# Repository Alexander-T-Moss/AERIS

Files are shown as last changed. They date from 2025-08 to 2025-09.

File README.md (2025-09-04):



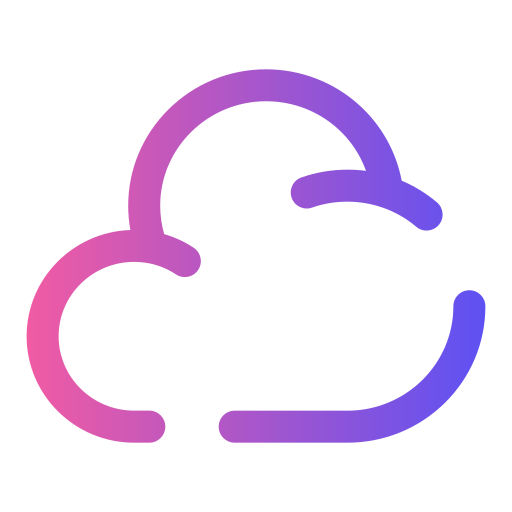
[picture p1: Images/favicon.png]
#  AERIS – Air Quality Monitoring System 






**AERIS** is an open-source air quality monitor built around an **ESP32** microcontroller, **SEN55** module and custom breakout board. It measures and reports environmental parameters, such as particulate matter, VOCs, humidity and temperature in real-time to either a Home Assistant instance (through ESPHome) or a local web app.

<br/>

## Project Goals
- **Accurate & Trustable Data** – Obtained by using the factory-calibrated SEN55 and thermally isolating the unit from the other electronics.
- **Low-Cost** – AERIS' DIY-friendly design approach and BOM considerations result in a unit cost that is more than halved when compared to equivalent off-the-shelf products, at only £35/€40/$48.
- **Full Hardware Utilisation** –  Using any of the provided firmware options, every last bit of information is extracted from AERIS, getting the most "bang-for-buck" out of the used hardware.
- **Simple Assembly** – From a snap-fit case to a breakout PCB, assembly is streamlined to require minimal tools and only a few minutes.
- **Accessible Project** - Care is taken to decrease friction from obtaining hardware to building an AERIS device. Unlike other monitors, AERIS can be used fully as a standalone unit without needing a Home Assistant instance. 

<br/>

## Feature List
<details>
<summary><b>Comprehensive Sensor Array</b></summary>
<br/>

- Temperature
- Relative Humidity
- Absolute Humidity (Approximation)
- VOC Index
- Particulate Matter
  - PM1.0
  - PM2.5
  - PM4.0
  - PM10.0
- Nitrogen Oxide Index (NOx)
- Carbon Dioxide (w/ Add-On Board)
- Atmospheric Pressure (w/ Add-On Board)

</details>

<details>
<summary><b>ESPHome Integration</b></summary>
<br/>  
Requires a Home Assistant instance; alternatively, AERIS can be operated without Home Assistant through its standalone mode.
<br/>
<br/>
</details>

<details>
<summary><b>Standalone Mode</b></summary>
<br/>
The ESP controller can host a local webpage, circumventing the need for a Home Assistant instance.
<br/> 
<br/>
</details>

<details>
<summary><b>1.54" OLED Display</b></summary>
<br/>
Configurable to either show key data at a glance or show in-depth information reported by AERIS.
<br/> 
<br/>
</details>

<details>
<summary><b>Snap-Fit Case</b></summary>
<br/>
For an easy assembly, reduced BOM and clean finish, the case is designed to snap-fit together.
<br/>
<br/>
</details>

<br/>

## More Information
Interested in this project or building an AERIS unit? Visit the [official documentation](https://aeris-docs.xyz) site for more info.

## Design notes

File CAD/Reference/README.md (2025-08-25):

# CAD Reference Sources

[Seeed Studio ESP32C3](https://grabcad.com/library/seeed-studio-xiao-esp32-c3-1) - *Seeed Studio XIAO-ESP32-C3.step*

[Sensirion SEN5x](https://sensirion.com/products/catalog/SEN55) - *Sensirion_STEP_SEN5x.STEP*

[Fan](https://grabcad.com/library/ld3007ms-fan-1) - *3007 5V FAN.step*

[BME280](https://grabcad.com/library/gy-bme280-1) - BME280.step

[SCD41](https://grabcad.com/library/sensirion-scd40-scd41-1) - SCD41.step

[SSD1309](https://grabcad.com/library/serial-spi-i2c-blue-1-54-inch-arduino-raspberry-pi-oled-display-128x64-1) - SSD1309 1.54' I2C.step

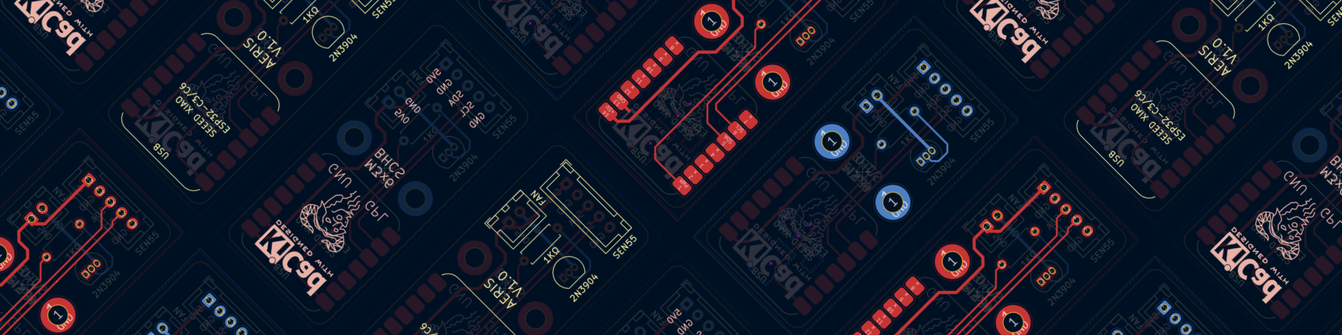
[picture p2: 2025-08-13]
Images/PCB_Schematic_Background.png

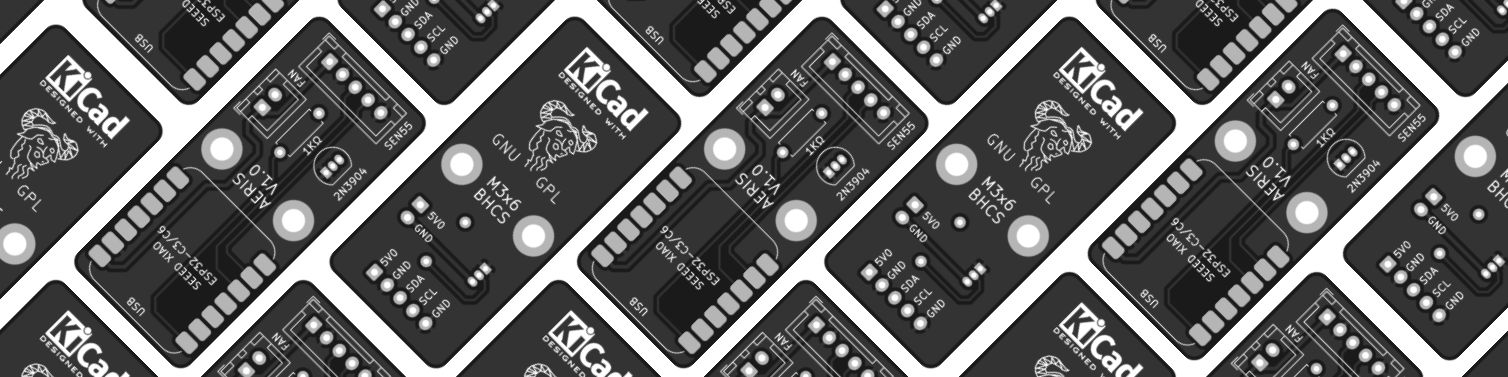
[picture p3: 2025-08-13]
Images/Gerber_Background.png

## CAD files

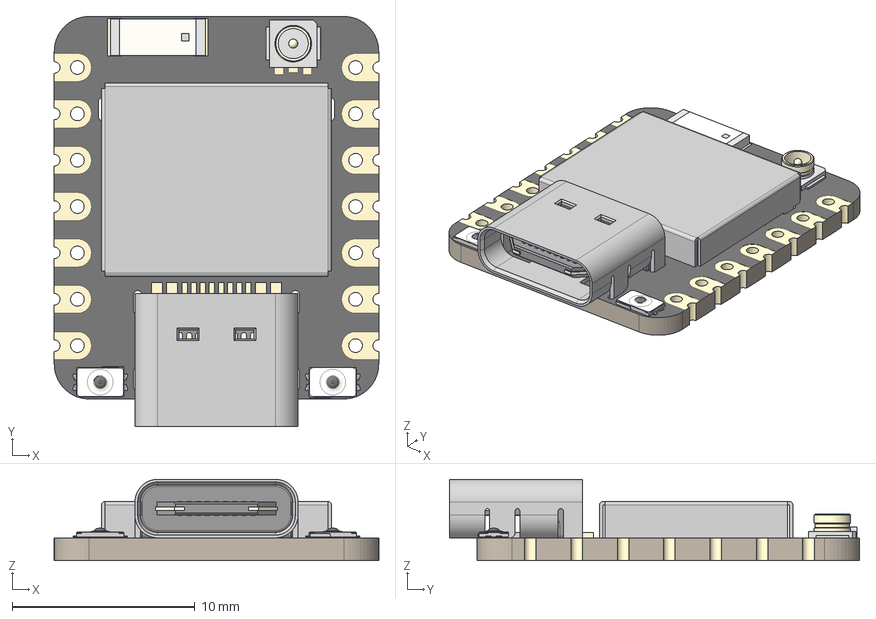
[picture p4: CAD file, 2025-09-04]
CAD/Reference/Seeed Studio XIAO ESP32-C6.step
17.8 x 22.5 x 4.46 mm
BOSS-EXTRUDE14_8_
BOSS-EXTRUDE7_4_
BOSS-EXTRUDE7_3_
BOSS-EXTRUDE14_4_
BOSS-EXTRUDE14_2_
BOSS-EXTRUDE14_11_
BOSS-EXTRUDE7_7_
BOSS-EXTRUDE14_9_
BOSS-EXTRUDE14_3_
BOSS-EXTRUDE14_7_
MIRROR2
BOSS-EXTRUDE14_5_
BOSS-EXTRUDE14_12_
BOSS-EXTRUDE7_8_
BOSS-EXTRUDE7_1_
BOSS-EXTRUDE14_10_
BOSS-EXTRUDE7_9_
BOSS-EXTRUDE14_6_
BOSS-EXTRUDE14_1_
BOSS-EXTRUDE7_6_
BOSS-EXTRUDE7_2_
CUT-EXTRUDE5
BOSS-EXTRUDE7_5_
U.FL Connector v1
Shield
SKTAAAE010 x 2
KH5220-A36 (Ceramic Antenna) v2

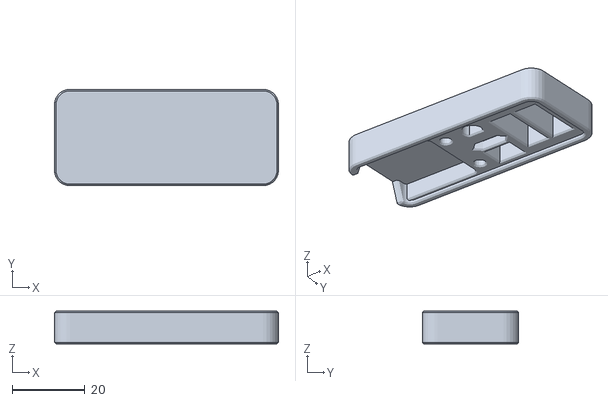
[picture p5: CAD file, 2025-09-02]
STLs/ESP32C3 Breakout Jig.stl
61.4 x 26.4 x 9.00

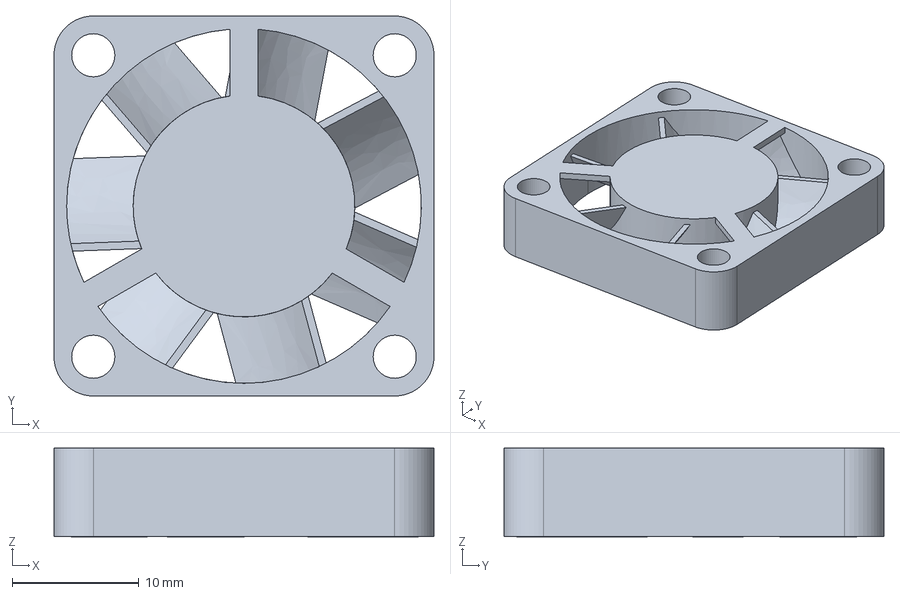
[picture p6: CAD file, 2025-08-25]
CAD/Reference/3007 5V Fan.step
30.0 x 30.0 x 7.02 mm

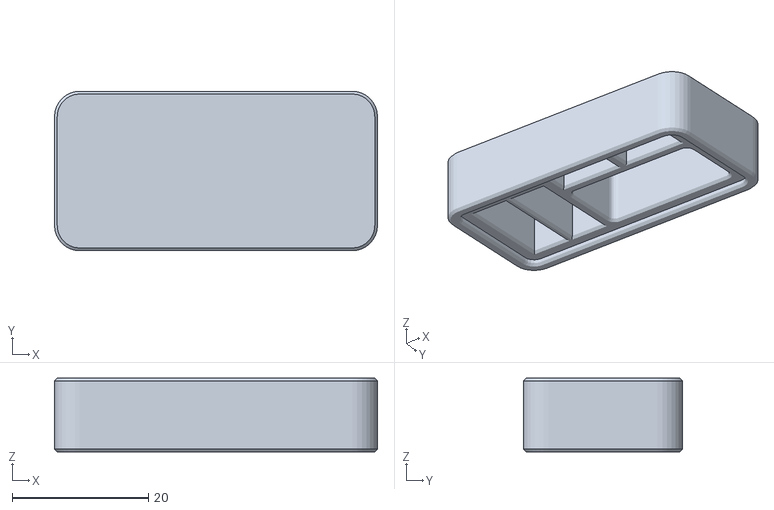
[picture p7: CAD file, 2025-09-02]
STLs/Add-On Solder Jig.stl
47.4 x 23.4 x 10.8

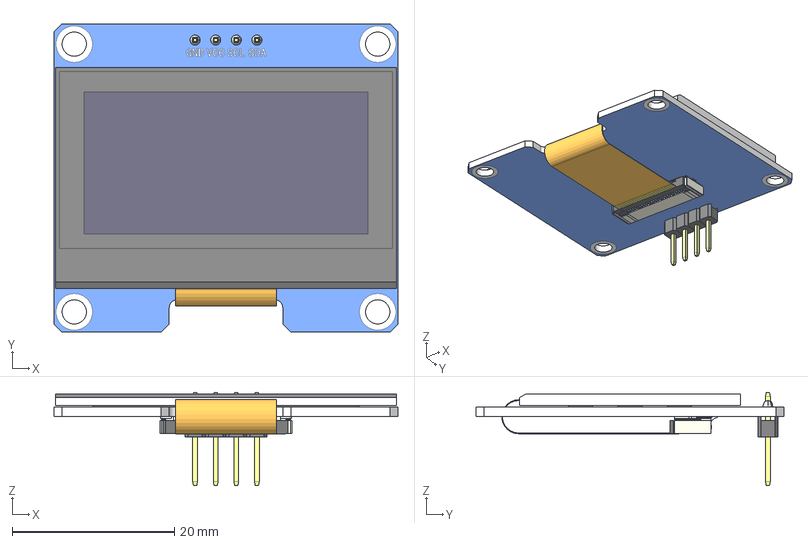
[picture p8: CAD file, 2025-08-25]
CAD/Reference/SSD1309 1.54' I2C.step
42.4 x 38.0 x 11.5 mm
0.15mm x 3
ER-OLEDM015-2-SPI-I2C PCB°å
ER-OLED015-2 (1)
ER-OLED015-2
FPC-24 (16)
FPC-24 (15)
FPC-24 (14)
FPC-24 (13)
FPC-24 (12)
FPC-24 (11)
FPC-24 (10)
FPC-24 (9)
FPC-24 (8)
FPC-24 (7)
FPC-24 (6)
FPC-24 (5)
FPC-24 (4)
FPC-24 (3)
FPC-24 (2)
FPC-24 (1)
FPC-24
Pin Header 7P (6)
Pin Header 7P (5)
Pin Header 7P (4)
Pin Header 7P (3)
Pin Header 7P (2)
Pin Header 7P (1)
Pin Header 7P

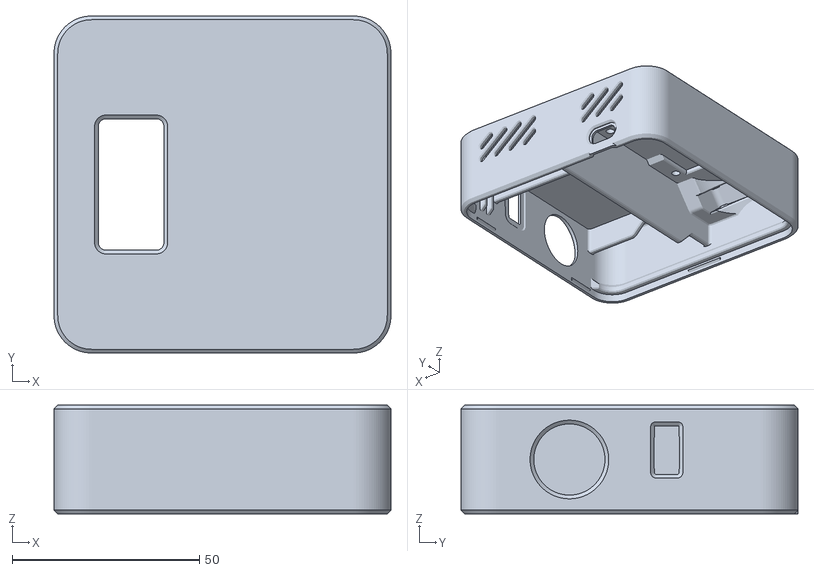
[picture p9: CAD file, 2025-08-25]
STLs/Cover.stl
90.0 x 90.0 x 29.0

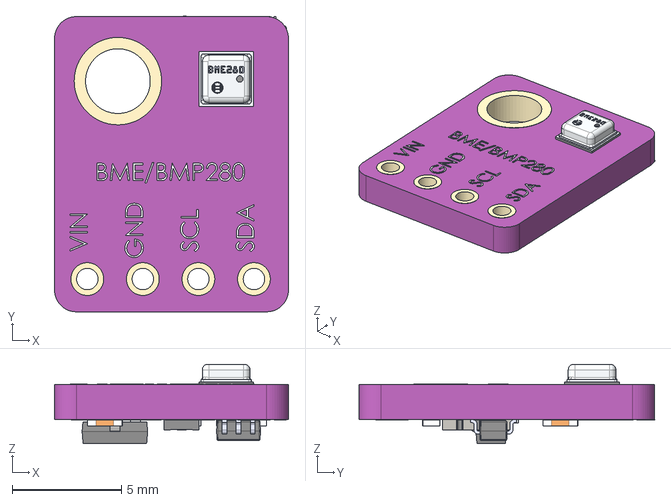
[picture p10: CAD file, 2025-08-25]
CAD/Reference/BME280.step
10.7 x 13.5 x 3.63 mm

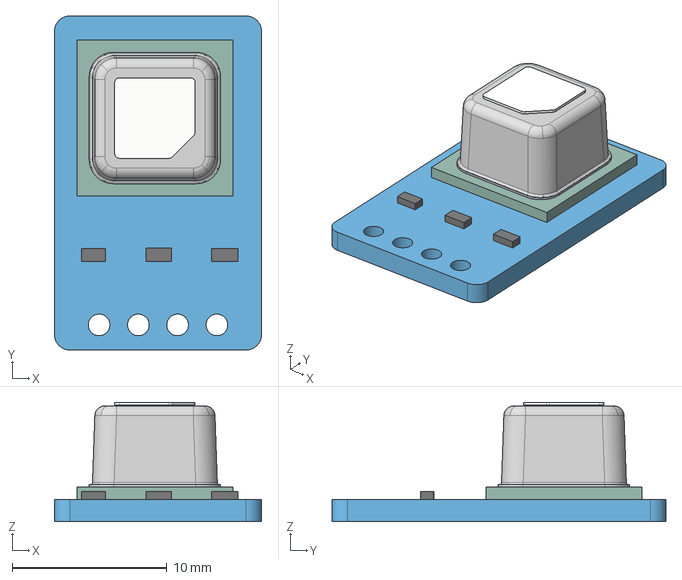
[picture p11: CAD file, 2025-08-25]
CAD/Reference/SCD41.step
13.4 x 21.6 x 7.72 mm

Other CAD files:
STLs/Base.stl

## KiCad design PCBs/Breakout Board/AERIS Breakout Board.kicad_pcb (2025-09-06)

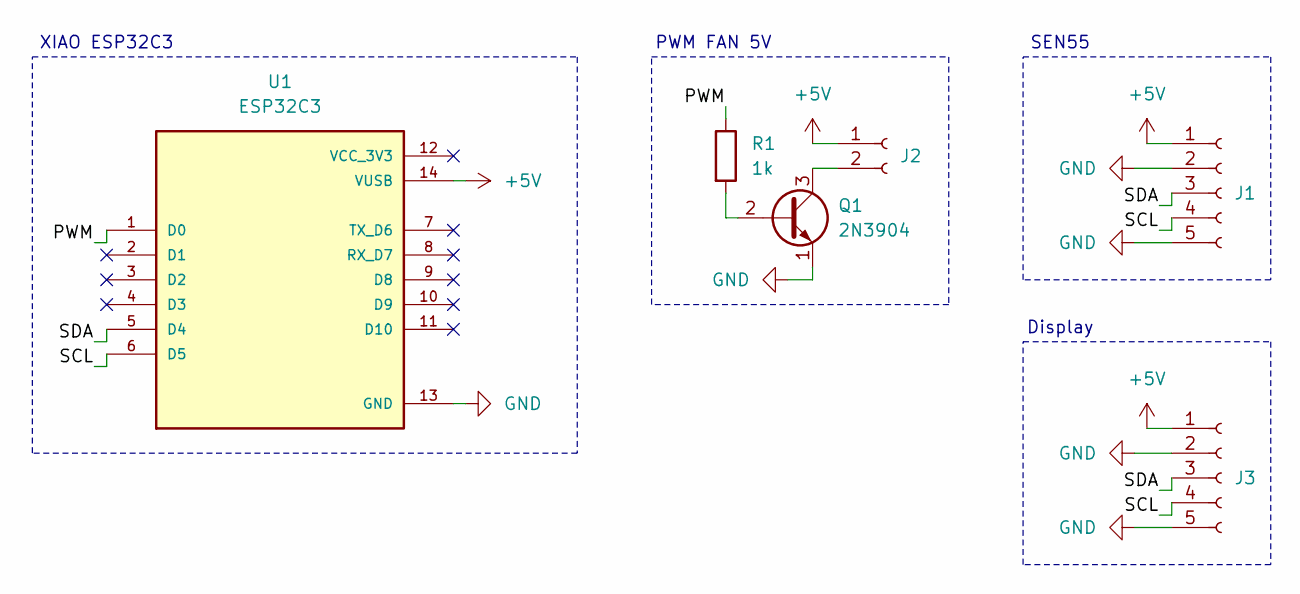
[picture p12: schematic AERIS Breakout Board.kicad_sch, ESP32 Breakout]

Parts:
J1, J3: Conn_01x05_Socket; JST_XH_B5B-XH-A_1x05_P2.50mm_Vertical
J2: Conn_01x02_Socket; JST_XH_B2B-XH-A_1x02_P2.50mm_Vertical
Q1: 2N3904; TO-92_Inline
R1: 1k; R_Axial_DIN0207_L6.3mm_D2.5mm_P7.62mm_Horizontal
U1: ESP32C3; XIAO_ESP32; PARTREV 23/05/2022

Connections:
+5V: J1.1, J2.1, J3.1, U1.14 (VUSB)
/PWM: R1.1, U1.1 (D0)
/SCL: J1.4, J3.4, U1.6 (D5)
/SDA: J1.3, J3.3, U1.5 (D4)
GND: J1.2, J1.5, J3.2, J3.5, Q1.1 (E), U1.13 (GND)
unnamed: J2.2, Q1.3 (C)
unnamed: Q1.2 (B), R1.2

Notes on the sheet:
SEN55
PWM FAN 5V
Display
XIAO ESP32C3

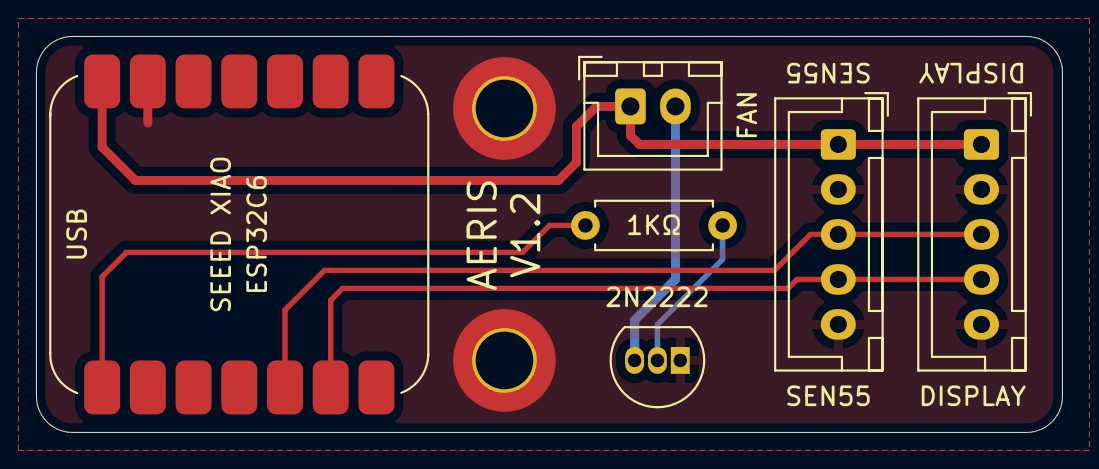
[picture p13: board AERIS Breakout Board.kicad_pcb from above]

Board: 2 copper layers, 57.0 x 22.0 mm, 6 parts (0 on the bottom side), 7 nets.

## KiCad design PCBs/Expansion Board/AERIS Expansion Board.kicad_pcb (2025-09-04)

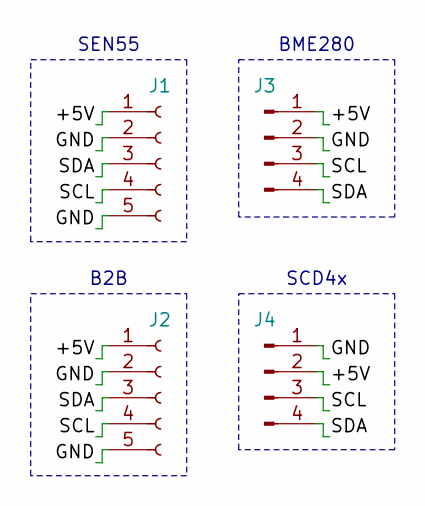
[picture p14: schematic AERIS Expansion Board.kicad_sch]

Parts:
J1, J2: Conn_01x05_Socket; JST_XH_B5B-XH-A_1x05_P2.50mm_Vertical
J3, J4: Conn_01x04_Pin; PinHeader_1x04_P2.54mm_Vertical

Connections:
/+5V: J1.1, J2.1, J3.1, J4.2
/GND: J1.2, J1.5, J2.2, J2.5, J3.2, J4.1
/SCL: J1.4, J2.4, J3.3, J4.3
/SDA: J1.3, J2.3, J3.4, J4.4

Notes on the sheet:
BME280
SCD4x
B2B
SEN55

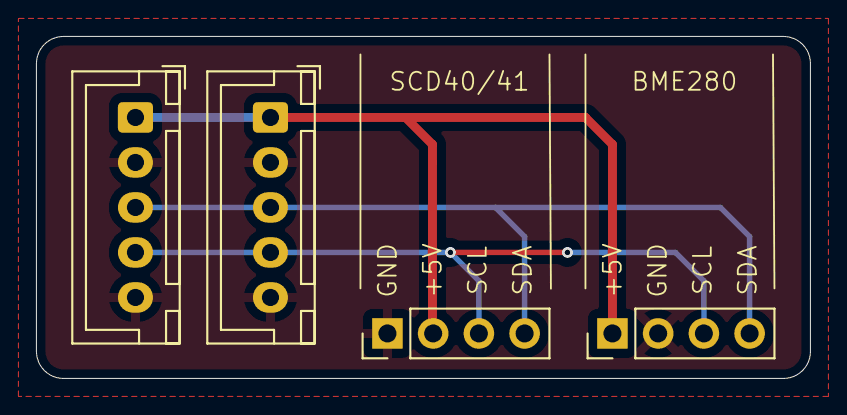
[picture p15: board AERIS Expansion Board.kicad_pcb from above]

Board: 2 copper layers, 43.0 x 19.0 mm, 4 parts (0 on the bottom side), 4 nets.

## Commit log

2025-07-31 Added Source CAD
    [Seeed Studio XIAO-ESP32-C3.step]
2025-08-12 Upload V1.0
    [ESP32 Breakout.kicad_pcb, ESP32 Breakout.kicad_sch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]
2025-08-12 Update ESP32 Breakout.kicad_sch
    [ESP32 Breakout.kicad_sch]
2025-08-13 Update ESP32 Breakout.kicad_pcb
    [ESP32 Breakout.kicad_pcb]
2025-08-13 File Update
    [ESP32 Breakout.kicad_pcb]
2025-08-13 Create Gerber Background Transparent.png
2025-08-22 Update to V1.1
    [ESP32 Breakout.kicad_pcb, ESP32 Breakout.kicad_sch]
2025-08-25 Update Breakout PCB To V1.2
    [AERIS Add-On Board.kicad_pcb, AERIS Add-On Board.kicad_sch, AERIS Breakout PCB.kicad_pcb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]
2025-08-25 File Restructure
    [AERIS Breakout PCB.kicad_pcb, AERIS Breakout PCB.kicad_sch, AERIS Expansion Board.kicad_pcb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]
2025-08-25 Uploaded CAD
    [3007 5V Fan.step, BME280.step, SCD41.step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]
2025-08-25 Upload STLs
    [Base.stl, Cover.stl]
2025-08-25 Remove duplicates
    [AERIS Expansion Board.kicad_pcb, JST-XH-Thru(V)-2Pin-2.54mm.stp, JST-XH-Thru(V)-5Pin-2.54mm.stp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]
2025-09-02 Update AERIS Expansion Board.kicad_pcb
    [AERIS Expansion Board.kicad_pcb]
2025-09-02 Added PCB CAD
    [AERIS Breakout Board.kicad_pcb, AERIS Expansion Board.kicad_pcb, Seeed Studio XIAO-ESP32-C3.step]
2025-09-02 Added Solder Jigs
    [Add-On Solder Jig.stl, ESP32C3 Breakout Jig.stl]
2025-09-04 Update PCBs
    Swap to just ESP32C6
    Make footprint libraries project and not global
    [AERIS Breakout Board.kicad_pcb, AERIS Expansion Board.kicad_pcb, Seeed Studio XIAO ESP32-C6.step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]
2025-09-06 Production Check
    [AERIS Breakout Board.kicad_pcb]

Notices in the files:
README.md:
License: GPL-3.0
